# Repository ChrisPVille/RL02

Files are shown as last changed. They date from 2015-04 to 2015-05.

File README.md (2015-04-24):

# RL02-USB Interface Project

## Overview

The aim of this project is to create an open-source interface between the DEC RL02 and a modern computer via USB.  

## Background

The RL02 hard drive was a mainstay of DEC's packaged computer systems in the late 1970s and 1980s.  Storing 10MB of data, these drives featured removable platters, 55ms average seek times, and ~250KBps effective linear throughput.  Combined with the modular design and longevity of the product line, there are still many functioning drives and many disk packs out there.

Of course, to interact with the data on these disk packs, a functioning drive is not enough.  Cables, interface cards, a DEC minicomputer, and software are all required, some of which has become very rare and prohibitively expensive when available.  The most cost-effective (and educational!) solution was to create a new interface connecting the drive directly to a [simulated minicomputer](http://simh.trailing-edge.com/) running on a PC.

In addition to the historical preservation aspects, people still operate vintage computers for fun and profit.  Setting up an operating system or transferring files can be an ordeal when they can only be moved via [Kermit](http://en.wikipedia.org/wiki/Kermit_%28protocol%29) or some other archaic medium.  This interface serves to obviate the need for such things by allowing the direct interface of the RL02 with a modern computer.

## The Interface

This interface uses an FPGA to do all drive-facing tasks such as MFM data decoding, clock recovery, drive state management, data buffering, etc.  The FPGA communicates with a microcontroller, exposing its data and a command interface over SPI.  That microcontroller serves as the USB mass storage/bulk transport device for the attached PC.

### FPGA

TODO: Expand

### Microcontroller

TODO: Expand

### PCB

TODO: Expand

## How to Update

```shell
echo TODO
```

## Building The Sources

TODO: Expand

(C) 2015 Christopher Parish

This program is free software: you can redistribute it and/or modify
it under the terms of the GNU General Public License as published by
the Free Software Foundation, either version 3 of the License, or
(at your option) any later version.  This is subject to the
exceptions listed in the LICENSE_EXCEPTION file.

This program is distributed in the hope that it will be useful,
but WITHOUT ANY WARRANTY; without even the implied warranty of
MERCHANTABILITY or FITNESS FOR A PARTICULAR PURPOSE.  See the
GNU General Public License for more details.

You should have received a copy of the GNU General Public License
along with this program.  If not, see <http://www.gnu.org/licenses/>.

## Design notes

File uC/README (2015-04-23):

Here is the Texas Instruments Code Composer Studio project used on the ARM micro-controller.  This is in prototype condition, suitable for trying different communication approaches and not architected in any particular manner (i.e. a complete mess).

In addition to CCS (http://processors.wiki.ti.com/index.php/Download_CCS), you will require the Tivaware Peripheral Driver Library and USB Library packages from TI (http://www.ti.com/tool/sw-tm4c).  On Linux, these EXEs can be sent to unzip directly.

I would prefer to host the drivers here, but TI has some hideous licensing verbiage on their drivers, preventing redistribution.  I might move away from them in the future because of it.

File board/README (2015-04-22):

This folder contains the KiCad (https://launchpad.net/kicad) project files, schematic symbols, and related footprints as well as generated schematics and gerber files.

I generally run the latest KiCad built from sources, so I may be using features that don't exist in the pre-built versions.

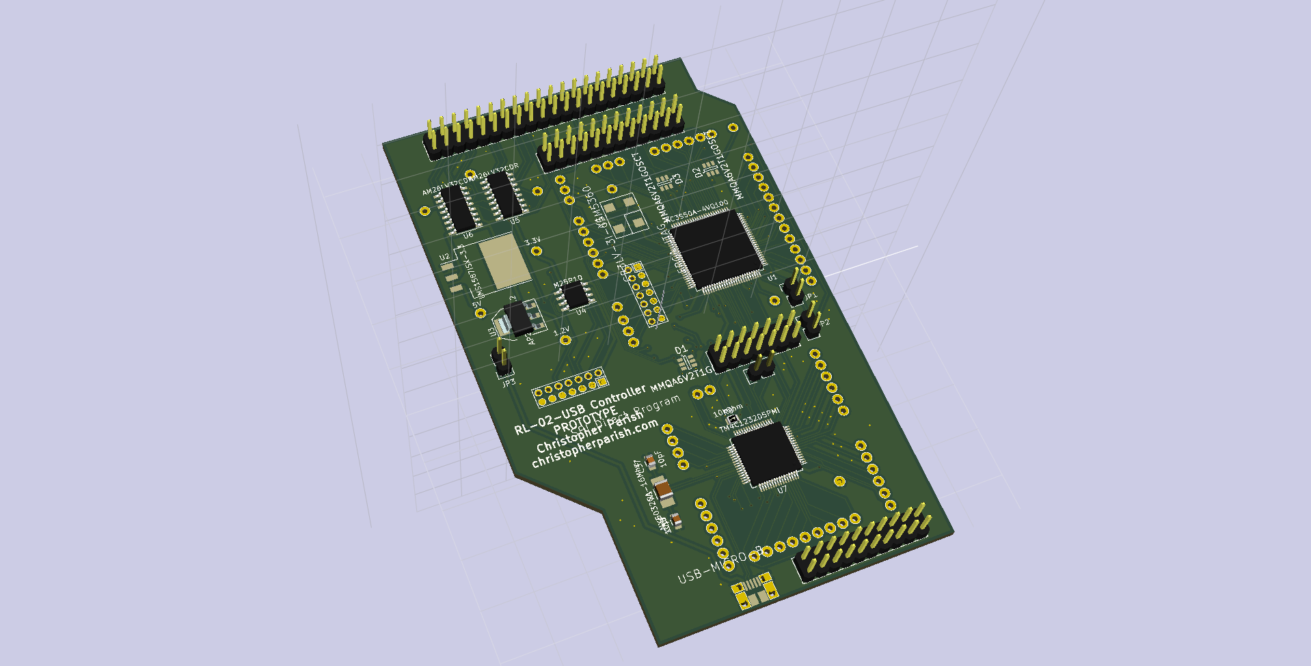
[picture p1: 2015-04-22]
board/Renders/First Prototype F.png

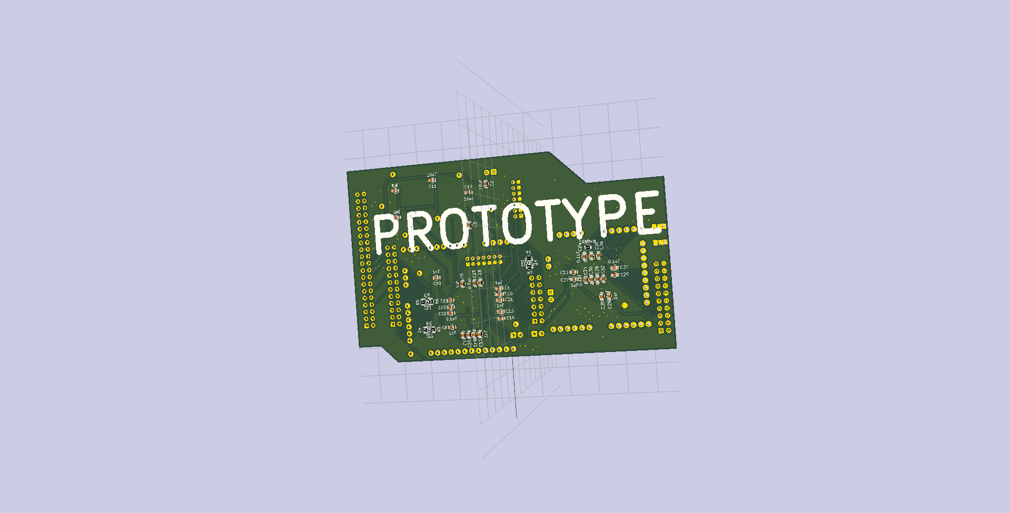
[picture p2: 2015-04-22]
board/Renders/First Prototype B.png

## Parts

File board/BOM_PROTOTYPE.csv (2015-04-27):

Digi-Key Part Number | Manufacturer | Manufacturer Part Number | Customer Reference | Quantity 1 | Quantity 2 | Quantity 3 | Mfg Std Lead Time | Description | Comments | RoHS Status | Lead Free Status | REACH Status
122-1592-ND | XILINX INC | XC3S50A-4VQG100C | MAIN FPGA | 1 | 0 | 0 | 18 Weeks | IC FPGA 68 I/O 100VQFP |  | RoHS Compliant | Lead free | Unaffected Dec-2014
296-35812-ND | TEXAS INSTRUMENTS | TM4C1232D5PMI | MAIN UC | 1 | 0 | 0 | 16 Weeks | IC MCU 32BIT 64KB FLASH 64LQFP | Alternate Packaging Exists | RoHS Compliant | Lead free | Unaffected Dec-2014
296-6794-1-ND | TEXAS INSTRUMENTS (VA) | AM26LV32CDR | DIFF RX | 2 | 0 | 0 | 6 Weeks | IC QUAD DIFF LINE RCVR 16-SOIC | Alternate Packaging Exists | RoHS Compliant | Lead free | Unaffected Dec-2014
CTX713LVCT-ND | CTS-FREQUENCY CONTROLS (VA) | CB3LV-3I-65M5360 | FPGA CLK | 1 | 0 | 0 | 6 Weeks | OSC XO 65.536MHZ HCMOS TTL SMD | Alternate Packaging Exists | RoHS Compliant | Lead free | Unaffected Jul-2011
AP2114HA-1.2TRG1DICT-ND | DIODES INCORPORATED (VA) | AP2114HA-1.2TRG1 | 1.2V LDO | 1 | 0 | 0 | 9 Weeks | IC REG LDO 1.2V 1A SOT223 | Alternate Packaging Exists | RoHS Compliant | Lead free | Unaffected Dec-2014
M25P10-AVMN6TPCT-ND | MICRON TECHNOLOGY INC (VA) | M25P10-AVMN6TP | FPGA FLASH | 1 | 0 | 0 | 12 Weeks | IC FLASH 1MBIT 50MHZ 8SO | Alternate Packaging Exists | RoHS Compliant | Lead free | Unaffected Aug-2011
644-1187-1-ND | NDK (VA) | NX5032GA-16MHZ-STD-CSK-4 | UC CRYSTAL | 1 | 0 | 0 | 8 Weeks | CRYSTAL 16.0000MHZ 8PF SMD | Alternate Packaging Exists | RoHS Compliant | Lead free by exemption | Unaffected Dec-2014
587-3512-1-ND | TAIYO YUDEN (VA) | UMK212BJ104KGHT |  | 12 | 0 | 0 | 5 Weeks | CAP CER 0.1UF 50V 10% X5R 0805 | Alternate Packaging Exists | RoHS Compliant | Lead free | Not Available
587-1300-1-ND | TAIYO YUDEN (VA) | LMK212BJ106KG-T |  | 4 | 0 | 0 | 5 Weeks | CAP CER 10UF 10V 10% X5R 0805 | Alternate Packaging Exists | RoHS Compliant | Lead free | Unaffected Nov-2009
587-1293-1-ND | TAIYO YUDEN (VA) | EMK212BJ225KG-T |  | 2 | 0 | 0 | 5 Weeks | CAP CER 2.2UF 16V 10% X5R 0805 | Alternate Packaging Exists | RoHS Compliant | Lead free | Unaffected Nov-2009
587-1291-1-ND | TAIYO YUDEN (VA) | TMK212BJ105KG-T |  | 25 | 0 | 0 | 5 Weeks | CAP CER 1UF 25V 10% X5R 0805 | Alternate Packaging Exists | RoHS Compliant | Lead free | Unaffected Nov-2009
609-3491-ND | FCI | 67996-114HLF | SPI JUMPERS | 1 | 0 | 0 | 6 Weeks | BERGSTIK II .100" DR STRAIGHT |  | RoHS Compliant | Lead free | Unaffected Dec-2012
609-3395-ND | FCI | 67997-224HLF | DRIVE DISCONNECT HEADER | 1 | 0 | 0 | 6 Weeks | CONN HEADER 24POS .100 STR 15AU |  | RoHS Compliant | Lead free | Unaffected Dec-2012
S9175-ND | SULLINS CONNECTOR SOLUTIONS | SBH11-PBPC-D20-ST-BK | DRIVE CONNECTOR | 1 | 0 | 0 | 4 Weeks | CONN HEADER 2.54MM 40POS GOLD |  | RoHS Compliant | Lead free | Unaffected Dec-2014
609-4050-1-ND | FCI (VA) | 10103594-0001LF |  | 1 | 0 | 0 | 9 Weeks | CONN RCPT STD MICRO USB TYPE B | Alternate Packaging Exists | RoHS Compliant | Lead free | Unaffected Dec-2012
311-1099-1-ND | YAGEO (VA) | CC0805JRNPO9BN100 |  | 3 | 0 | 0 | 20 Weeks | CAP CER 10PF 50V 5% NPO 0805 | Alternate Packaging Exists | RoHS Compliant | Lead free | Unaffected Jun-2014
311-10.0KCRCT-ND | YAGEO (VA) | RC0805FR-0710KL |  | 3 | 0 | 0 | 22 Weeks | RES SMD 10K OHM 1% 1/8W 0805 | Alternate Packaging Exists | RoHS Compliant | Lead free | Unaffected Jun-2014
S9172-ND | SULLINS CONNECTOR SOLUTIONS | SBH11-PBPC-D10-ST-BK | UC JTAG | 1 | 0 | 0 | 4 Weeks | CONN HEADER 2.54MM 20POS GOLD |  | RoHS Compliant | Lead free | Unaffected Dec-2014
MMQA6V2T1GOSCT-ND | ON SEMICONDUCTOR (VA) | MMQA6V2T1G | ESD DIODES | 3 | 0 | 0 | 4 Weeks | TVS DIODE 4VWM 9VC SC74-6 | Alternate Packaging Exists | RoHS Compliant | Lead free | Unaffected Dec-2014
AP2114H-3.3TRG1DICT-ND | DIODES INCORPORATED (VA) | AP2114H-3.3TRG1 | 3.3V REG | 1 | 0 | 0 | 9 Weeks | IC REG LDO 3.3V 1A SOT223 | Alternate Packaging Exists | RoHS Compliant | Lead free | Unaffected Dec-2014
RHM330KCT-ND | ROHM SEMICONDUCTOR (PASSIVE) (VA) | ESR10EZPJ331 | TERMINATION RESISTORS | 26 | 0 | 0 | 6-8 Weeks | RES SMD 330 OHM 5% 0.4W 0805 | Alternate Packaging Exists | RoHS Compliant | Lead free | Unaffected Jun-2012

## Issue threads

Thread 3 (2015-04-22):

Bad sector remapping in USB MSC mode

ChrisPVille, 2015-04-22:
Modern OSes get unhappy when they have to deal with IO errors from disks.  The RL02 disk packs pretty much all had bad sectors somewhere.  These can be identified and stored in a factory provided table on the last track of the disk, but it was up to each OS to decide how to handle them.  Some skip sectors while others remap them.

In USB Mass Storage mode, save a track of the RL02 for sector remapping and use the DEC written bad sector table.  With these, modern filesystems can be written to the disk around the inevitable bad sectors, although this will break SIMH and block level disk backup support for vintage disks.

smaresca, 2017-04-14:
@ChrisPVille I'm curious: have you revisited this item by any chance?

ChrisPVille, 2017-05-14:
Nope. I haven't worked on the hard drive project in a while.  It was becoming a major headache to constantly repair the age-related problems that kept popping up in the drive as I was trying to build this.  I did pick up a few more RL-02s in the interim, and I will get back to working on this... eventually.

As far as the bad sector map, I don't think it needs to be in the DEC format.  I suspect any drive being used in MSC mode is not ever going to be fully compatible with the PDP-11 emulators.  Because the emulated software (RT-11, etc.) handles bad sectors internally, it would be an ugly process of decoding the DEC bad sector format on the disk, managing that from the microcontroller, communicating that through a side-channel to a modified SimH which would feed that through to the guest OS where any failing writes to bad sectors would get communicated back to the uC for inclusion on that table.

It makes more sense to have MSC mode (LBA) available for modern filesystems which can handle their own bad blocks and provide a special SimH driver exposing the underlying Cylinder Head Sector format a virtual RL11 controller would have.  The microcontroller never has to worry about marking or relocating bad blocks as higher level pieces of software will do that.

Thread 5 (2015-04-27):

Incorrect 3.3V Regulator

ChrisPVille, 2015-04-27:
The BOM has the wrong 3.3V regulator specified for the physical footprint.

Either find a pin compatible replacement or pick a new part.

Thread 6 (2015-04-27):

Anomalous drive fault after spindown

ChrisPVille, 2015-04-27:
Every once in a while the drive asserts a non-resettable fault after sitting idle, post-spindown, for a while.  It seems to spontaneously disappear before I go to probe it.  It might be an electrical margin issue.

Write some code and modify the FPGA to interrupt the microcontroller so it can capture the error condition the instant it happens, before it goes away.  This type of error handing will be required for robustness anyway.

ChrisPVille, 2015-05-03:
Quickly poking around, it looks like spin error gets asserted by the drive.  This is probably an issue with the actual drive logic board, as spin error isn't supposed to assert on spin-down (because that would be dumb).

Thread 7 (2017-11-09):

RL02 Terminator - is it necessary?

AaronJackson, 2017-11-09:
Hi Chris,
I saw the video about this project on Hackaday and it didn't look like you had a terminator attached. Is one actually needed? I've been trying to get an RL02 drive to work with my 11/73 but not having much luck. Thanks and great job with this project.

ChrisPVille, 2017-11-10:
The cable run between my controller card and the drive was around 15cm, under any length where I needed to worry about transmission line effects.  Like the DEC RL11, my controller card has termination resistors on it, which should help quell reflections somewhat.

The system clock is a leisurely 4.1Mhz although the write MFM signal should probably be modeled as ~100Mhz because of the tiny phase shifts caused by write pre-compensation.  Still, at 100Mhz the drive will probably work sans terminator read/write with cable lengths in the low 10s of cm and read-only out over a meter.  As with all things RF, YMMV.

If you find you really need a terminator and can't find an official one (it took me two years to find one), you can build a PCB with the appropriate value termination resistors and connect the internal ribbon cable to it as I believe @NF6X did for his RL-02 interface project [here](https://github.com/NF6X/RL02-USB/tree/master/pcbs/RL02-USB-terminator).

AaronJackson, 2017-11-10:
Thanks Chris. That's very useful information. I had tried building a terminator but I am beginning to think I'm either very bad at geometry or there is an issue with the drive.

Closed 2017-11-10.

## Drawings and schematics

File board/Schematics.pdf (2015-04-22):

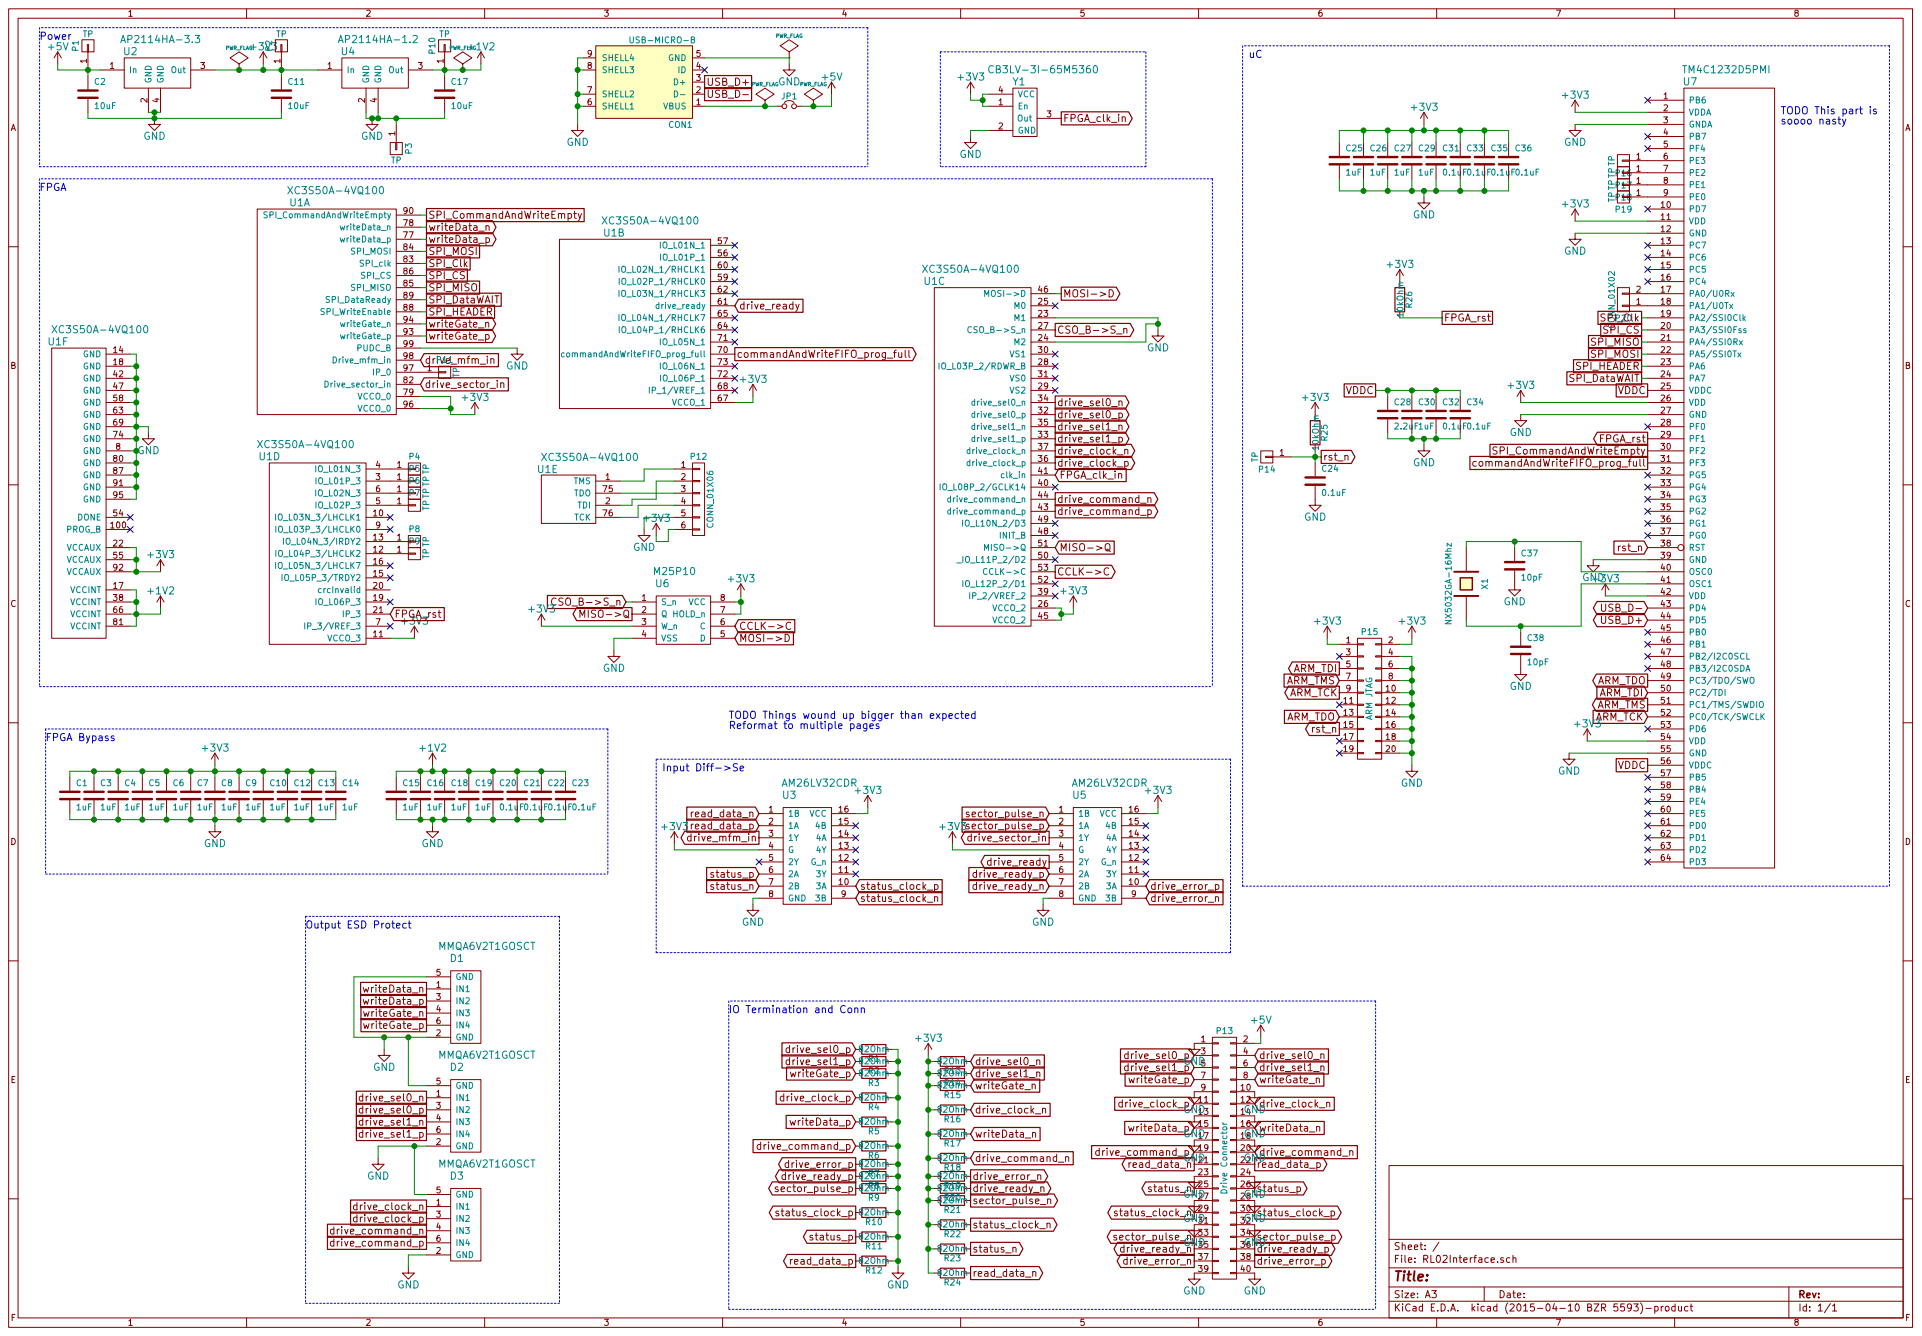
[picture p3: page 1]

4 U2AP2114HA-3.3 TODO This part is

TODO Things wound up bigger than expected
Reformat to multiple pages

Id: 1/1 Title: File: RL02Interface.sch Sheet: /

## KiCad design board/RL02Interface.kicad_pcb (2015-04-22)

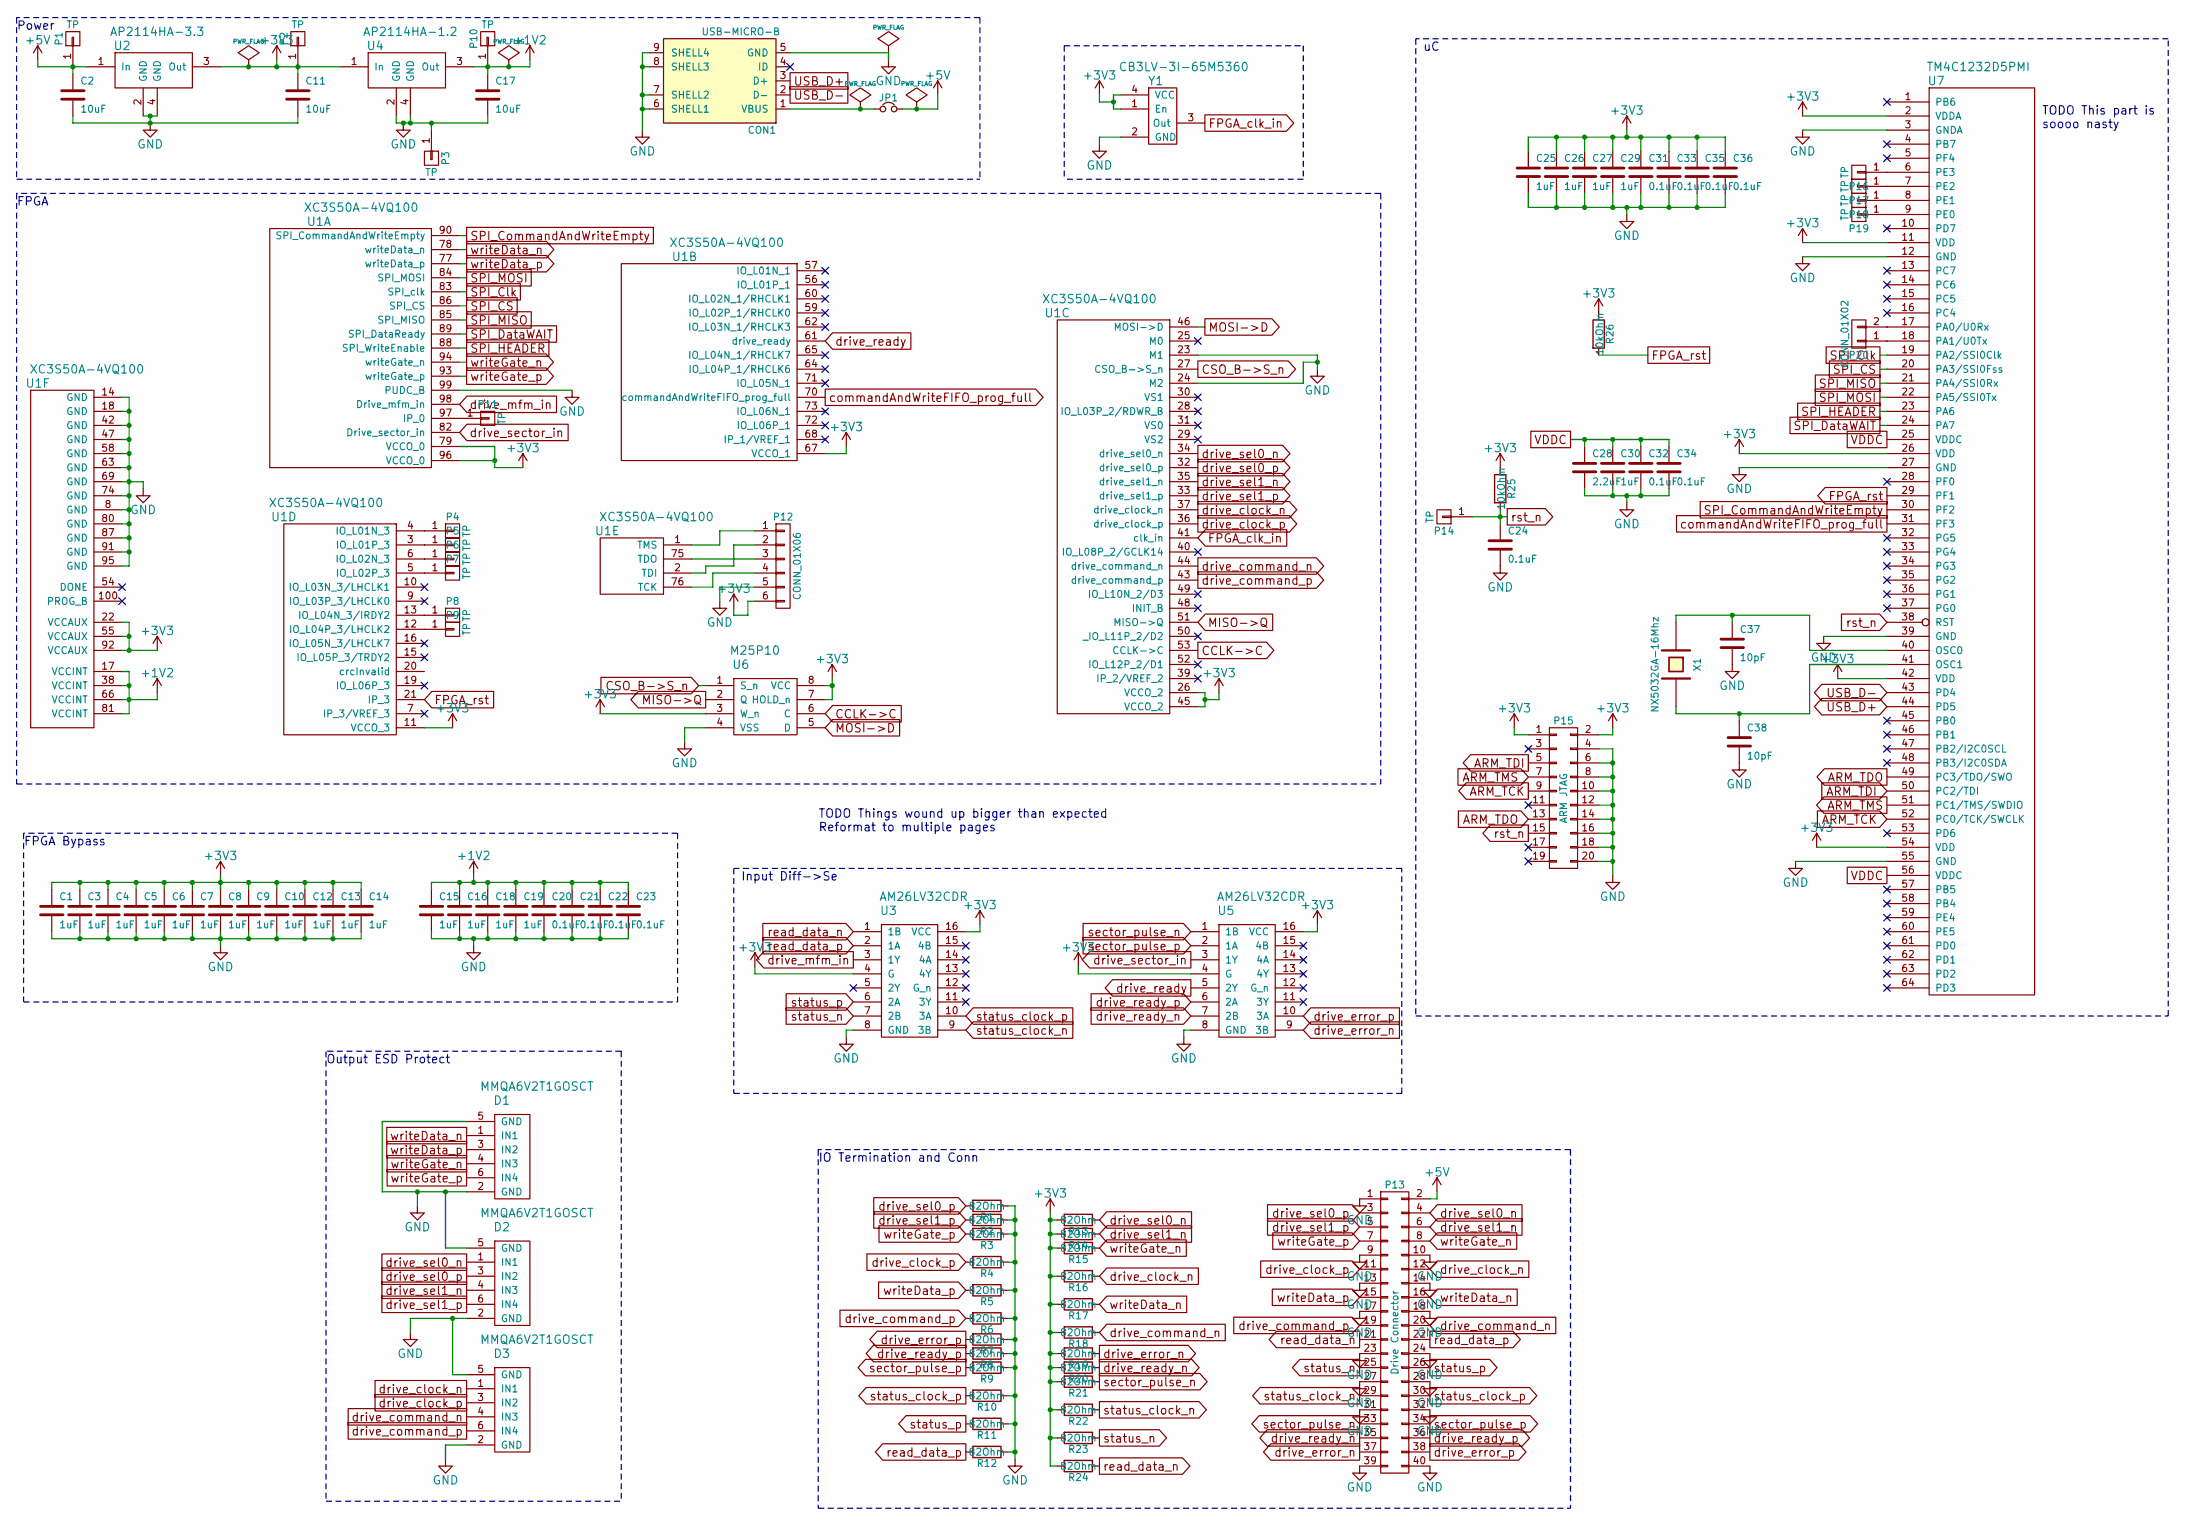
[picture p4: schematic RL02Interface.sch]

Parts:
C1, C3, C4, C5, C6, C7, C8, C9, C10, C12, C13, C14, C15, C16, C18, C19, C25, C26, C27, C29, C30: 1uF; C_0805
C2, C11, C17: 10uF; C_0805
C20, C21, C22, C23, C24, C31, C32, C33, C34, C35, C36: 0.1uF; C_0805
C28: 2.2uF; C_0805
C37, C38: 10pF; C_0805
CON1: USB-MICRO-B; MicroUSB-B
D1, D2, D3: MMQA6V2T1GOSCT; SOT-23-6
JP1: Jumper_NC_Small; Pin_Header_Straight_1x02
P1, P2, P3, P4, P5, P6, P7, P8, P9, P10, P11, P14, P16, P17, P18, P19: TP
P12: CONN_01X06; Pin_Header_Straight_1x06
P13: Drive Connector; Pin_Header_Straight_2x20
P15: ARM JTAG; Pin_Header_Straight_2x10
P20: CONN_01X02; Pin_Header_Straight_1x02
R1, R2, R3, R4, R5, R6, R7, R8, R9, R10, R11, R12, R13, R14, R15, R16, R17, R18, R19, R20, R21, R22, R23, R24: 82Ohm; R_0805
R25, R26: 10kOhm; R_0805
U1: XC3S50A-4VQ100; TQFP-100_14x14mm_Pitch0.5mm
U2: AP2114HA-3.3; SOT-223
U3, U5: AM26LV32CDR; SOIC-16_3.9x9.9mm_Pitch1.27mm
U4: AP2114HA-1.2; SOT-223
U6: M25P10; SOIC-8_3.9x4.9mm_Pitch1.27mm
U7: TM4C1232D5PMI; TQFP-64_10x10mm_Pitch0.5mm
X1: NX5032GA-16Mhz; C_1210_HandSoldering
Y1: CB3LV-3I-65M5360; CTSCrystal

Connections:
+1V2: C15.1, C16.1, C17.1, C18.1, C19.1, C20.1, C21.1, C22.1, C23.1, P10.1, U1.17 (VCCINT), U1.38 (VCCINT), U1.66 (VCCINT), U1.81 (VCCINT), U4.3 (Out); also elsewhere on the board
+3V3: C1.1, C3.1, C4.1, C5.1, C6.1, C7.1, C8.1, C9.1, C10.1, C11.1, C12.1, C13.1, C14.1, C25.1, C26.1, C27.1, C29.1, C31.1, C33.1, C35.1, C36.1, P2.1, P12.6, P15.1, P15.2, R13.2, R14.2, R15.2, R16.2, R17.2, R18.2, R19.2, R20.2, R21.2, R22.2, R23.2, R24.2, R25.1, R26.1, U1.11 (VCCO_3), U1.22 (VCCAUX), U1.26 (VCCO_2), U1.45 (VCCO_2), U1.55 (VCCAUX), U1.67 (VCCO_1), U1.79 (VCCO_0), U1.92 (VCCAUX), U1.96 (VCCO_0), U2.3 (Out), U3.4 (G), U3.16 (VCC), U4.1 (In), U5.4 (G), U5.16 (VCC), U6.3 (W_n), U6.7 (HOLD_n), U6.8 (VCC), U7.2 (VDDA), U7.11 (VDD), U7.26 (VDD), U7.42 (VDD), U7.54 (VDD), Y1.1 (En), Y1.4 (VCC); also elsewhere on the board
+5V: C2.1, JP1.2, P1.1, P13.2, U2.1 (In); also elsewhere on the board
ARM_TCK: P15.9, U7.52 (PC0/TCK/SWCLK)
ARM_TDI: P15.5, U7.50 (PC2/TDI)
ARM_TDO: P15.13, U7.49 (PC3/TDO/SWO)
ARM_TMS: P15.7, U7.51 (PC1/TMS/SWDIO)
CCLK->C: U1.53 (CCLK->C), U6.6 (C)
CSO_B->S_n: U1.27 (CSO_B->S_n), U6.1 (S_n)
FPGA_clk_in: U1.41 (clk_in), Y1.3 (Out)
FPGA_rst: R26.2, U1.21 (IP_3), U7.29 (PF1)
GND: C1.2, C2.2, C3.2, C4.2, C5.2, C6.2, C7.2, C8.2, C9.2, C10.2, C11.2, C12.2, C13.2, C14.2, C15.2, C16.2, C17.2, C18.2, C19.2, C20.2, C21.2, C22.2, C23.2, C24.2, C25.2, C26.2, C27.2, C28.2, C29.2, C30.2, C31.2, C32.2, C33.2, C34.2, C35.2, C36.2, C37.2, C38.2, CON1.5 (GND), CON1.6 (SHELL1), CON1.7 (SHELL2), CON1.8 (SHELL3), CON1.9 (SHELL4), CON1.PAD, D1.2 (GND), D1.5 (GND), D2.2 (GND), D2.5 (GND), D3.2 (GND), D3.5 (GND), P3.1, P12.5, P13.1, P13.9, P13.10, P13.13, P13.14, P13.17, P13.18, P13.23, P13.24, P13.27, P13.28, P13.31, P13.32, P13.39, P13.40, P15.4, P15.6, P15.8, P15.10, P15.12, P15.14, P15.16, P15.18, P15.20, R1.1, R2.1, R3.1, R4.1, R5.1, R6.1, R7.1, R8.1, R9.1, R10.1, R11.1, R12.1, U1.8 (GND), U1.14 (GND), U1.18 (GND), U1.23 (M1), U1.24 (M2), U1.42 (GND), U1.47 (GND), U1.58 (GND), U1.63 (GND), U1.69 (GND), U1.74 (GND), U1.80 (GND), U1.87 (GND), U1.91 (GND), U1.95 (GND), U1.99 (PUDC_B), U2.2 (GND), U2.4 (GND), U3.8 (GND), U4.2 (GND), U4.4 (GND), U5.8 (GND), U6.4 (VSS), U7.3 (GNDA), U7.12 (GND), U7.27 (GND), U7.39 (GND), U7.55 (GND), Y1.2 (GND); also elsewhere on the board
MISO->Q: U1.51 (MISO->Q), U6.2 (Q)
MOSI->D: U1.46 (MOSI->D), U6.5 (D)
unnamed: C37.1, U7.40 (OSC0), X1.1
unnamed: C38.1, U7.41 (OSC1), X1.2
unnamed: CON1.1 (VBUS), JP1.1
unnamed: P4.1, U1.4 (IO_L01N_3)
unnamed: P5.1, U1.3 (IO_L01P_3)
unnamed: P6.1, U1.6 (IO_L02N_3)
unnamed: P7.1, U1.5 (IO_L02P_3)
unnamed: P8.1, U1.13 (IO_L04N_3/IRDY2)
unnamed: P9.1, U1.12 (IO_L04P_3/LHCLK2)
unnamed: P11.1, U1.97 (IP_0)
unnamed: P12.1, U1.1 (TMS)
unnamed: P12.2, U1.2 (TDI)
unnamed: P12.3, U1.75 (TDO)
unnamed: P12.4, U1.76 (TCK)
unnamed: P16.1, U7.6 (PE3)
unnamed: P17.1, U7.7 (PE2)
unnamed: P18.1, U7.8 (PE1)
unnamed: P19.1, U7.9 (PE0)
unnamed: P20.1, U7.18 (PA1/U0Tx)
unnamed: P20.2, U7.17 (PA0/U0Rx)
SPI_CS: U1.86 (SPI_CS), U7.20 (PA3/SSI0Fss)
SPI_Clk: U1.83 (SPI_clk), U7.19 (PA2/SSI0Clk)
SPI_CommandAndWriteEmpty: U1.90 (SPI_CommandAndWriteEmpty), U7.30 (PF2)
SPI_DataWAIT: U1.89 (SPI_DataReady), U7.24 (PA7)
SPI_HEADER: U1.88 (SPI_WriteEnable), U7.23 (PA6)
SPI_MISO: U1.85 (SPI_MISO), U7.21 (PA4/SSI0Rx)
SPI_MOSI: U1.84 (SPI_MOSI), U7.22 (PA5/SSI0Tx)
USB_D+: CON1.3 (D+), U7.44 (PD5)
USB_D-: CON1.2 (D-), U7.43 (PD4)
VDDC: C28.1, C30.1, C32.1, C34.1, U7.25 (VDDC), U7.56 (VDDC)
commandAndWriteFIFO_prog_full: U1.70 (commandAndWriteFIFO_prog_full), U7.31 (PF3)
drive_clock_n: D3.1 (IN1), P13.12, R16.1, U1.37 (drive_clock_n)
drive_clock_p: D3.3 (IN2), P13.11, R4.2, U1.36 (drive_clock_p)
drive_command_n: D3.4 (IN3), P13.20, R18.1, U1.44 (drive_command_n)
drive_command_p: D3.6 (IN4), P13.19, R6.2, U1.43 (drive_command_p)
drive_error_n: P13.37, R19.1, U5.9 (3B)
drive_error_p: P13.38, R7.2, U5.10 (3A)
drive_mfm_in: U1.98 (Drive_mfm_in), U3.3 (1Y)
drive_ready: U1.61 (drive_ready), U5.5 (2Y)
drive_ready_n: P13.35, R20.1, U5.7 (2B)
drive_ready_p: P13.36, R8.2, U5.6 (2A)
drive_sector_in: U1.82 (Drive_sector_in), U5.3 (1Y)
drive_sel0_n: D2.1 (IN1), P13.4, R13.1, U1.34 (drive_sel0_n)
drive_sel0_p: D2.3 (IN2), P13.3, R1.2, U1.32 (drive_sel0_p)
drive_sel1_n: D2.4 (IN3), P13.6, R14.1, U1.35 (drive_sel1_n)
drive_sel1_p: D2.6 (IN4), P13.5, R2.2, U1.33 (drive_sel1_p)
read_data_n: P13.21, R24.1, U3.1 (1B)
read_data_p: P13.22, R12.2, U3.2 (1A)
rst_n: C24.1, P14.1, P15.15, R25.2, U7.38 (RST); also elsewhere on the board
sector_pulse_n: P13.33, R21.1, U5.1 (1B)
sector_pulse_p: P13.34, R9.2, U5.2 (1A)
status_clock_n: P13.29, R22.1, U3.9 (3B)
status_clock_p: P13.30, R10.2, U3.10 (3A)
status_n: P13.25, R23.1, U3.7 (2B)
status_p: P13.26, R11.2, U3.6 (2A)
writeData_n: D1.1 (IN1), P13.16, R17.1, U1.78 (writeData_n)
writeData_p: D1.3 (IN2), P13.15, R5.2, U1.77 (writeData_p)
writeGate_n: D1.4 (IN3), P13.8, R15.1, U1.94 (writeGate_n)
writeGate_p: D1.6 (IN4), P13.7, R3.2, U1.93 (writeGate_p)

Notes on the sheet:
TODO This part is soooo nasty
TODO Things wound up bigger than expected Reformat to multiple pages
FPGA
Power
FPGA Bypass
Output ESD Protect
IO Termination and Conn
Input Diff->Se

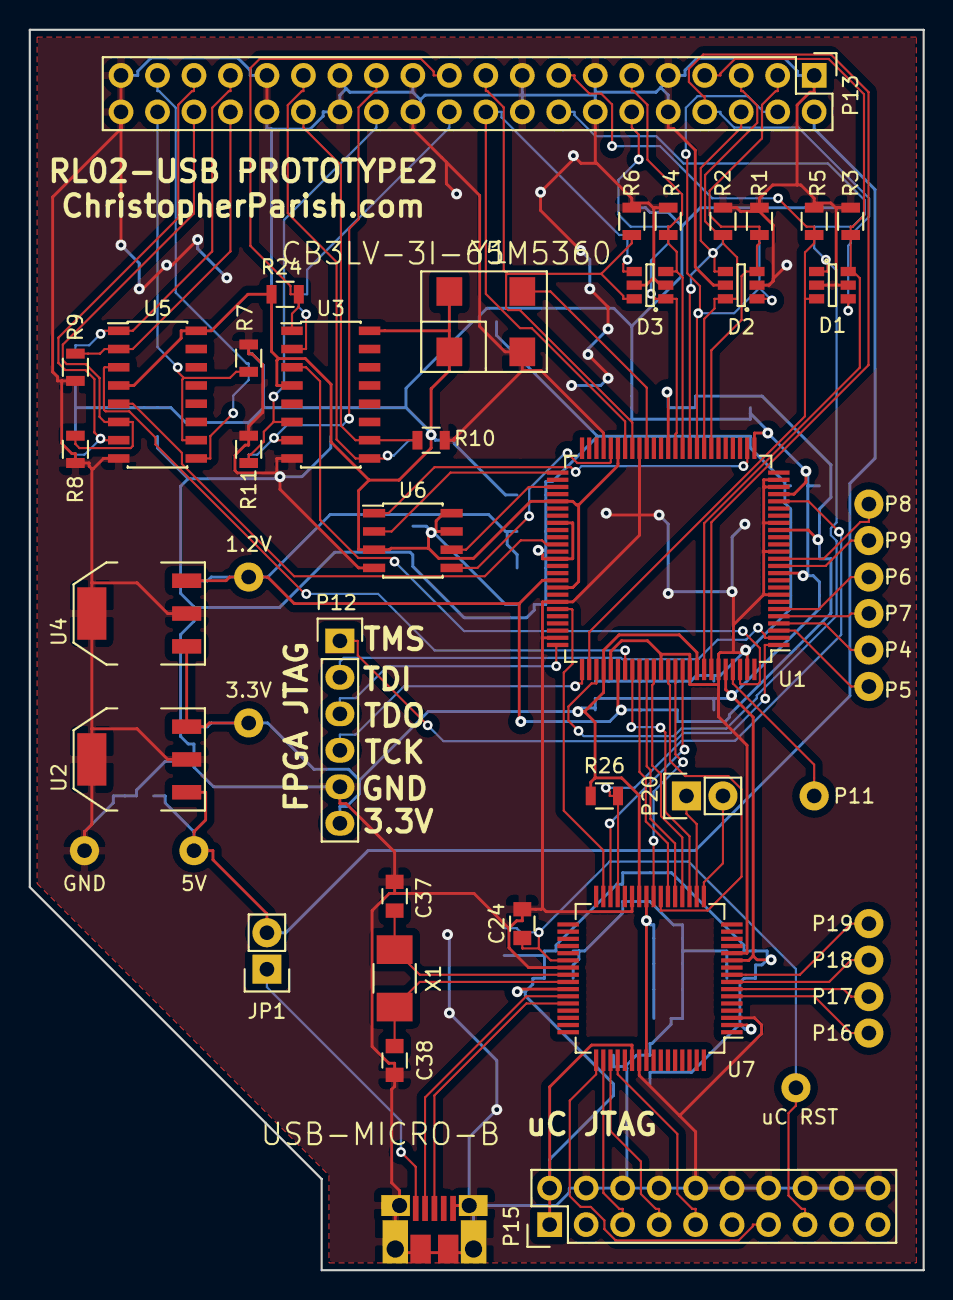
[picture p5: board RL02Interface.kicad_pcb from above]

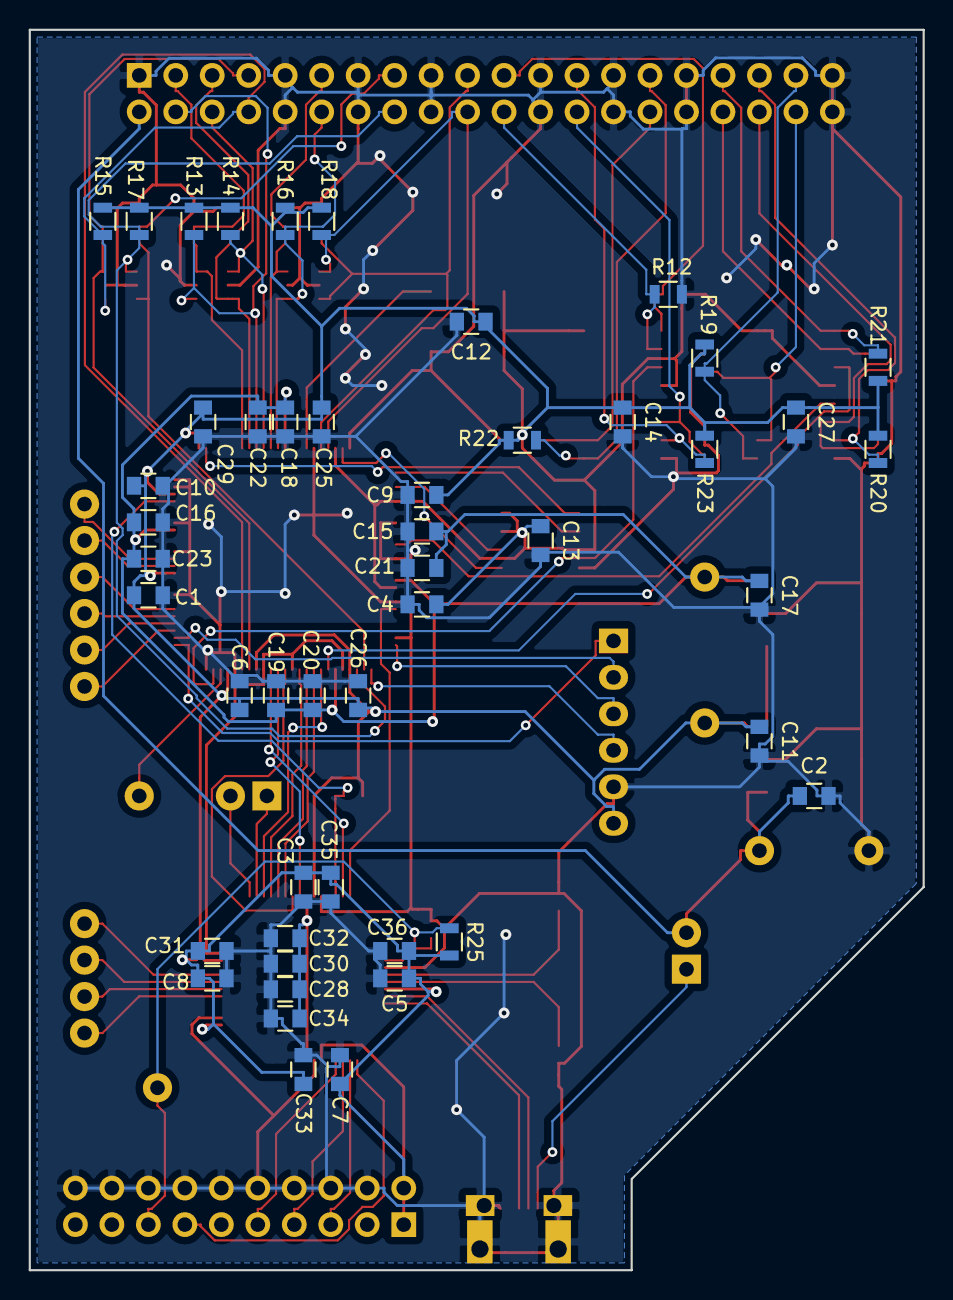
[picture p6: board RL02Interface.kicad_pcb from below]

Board: 2 copper layers, 62.2 x 86.4 mm, 98 parts (48 on the bottom side), 73 nets.

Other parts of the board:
1.2V, 3.3V, 5V: TP
GND: TP
uC RST: TP

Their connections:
+1V2: 1.2V.1; also elsewhere on the board
+3V3: 3.3V.1; also elsewhere on the board
+5V: 5V.1; also elsewhere on the board
GND: GND.1; also elsewhere on the board
rst_n: uC RST.1; also elsewhere on the board

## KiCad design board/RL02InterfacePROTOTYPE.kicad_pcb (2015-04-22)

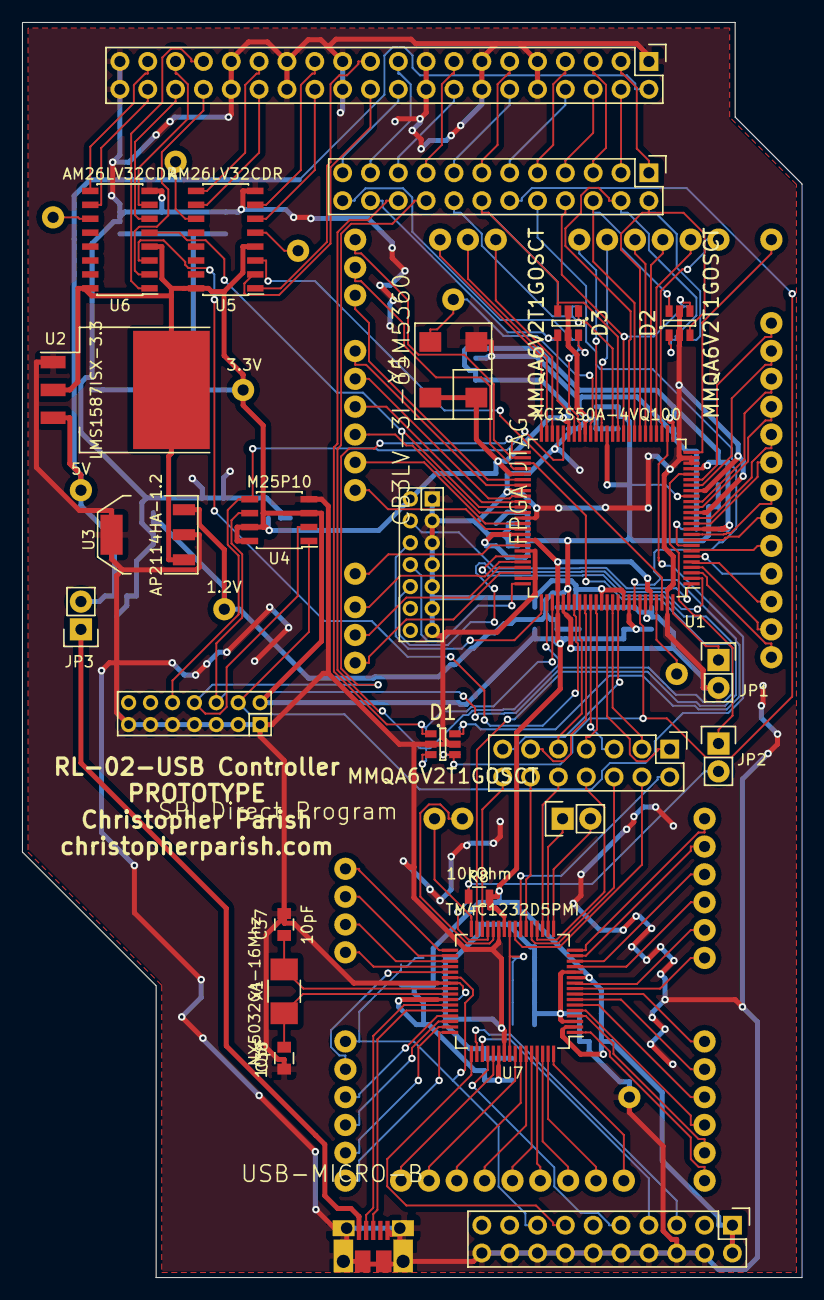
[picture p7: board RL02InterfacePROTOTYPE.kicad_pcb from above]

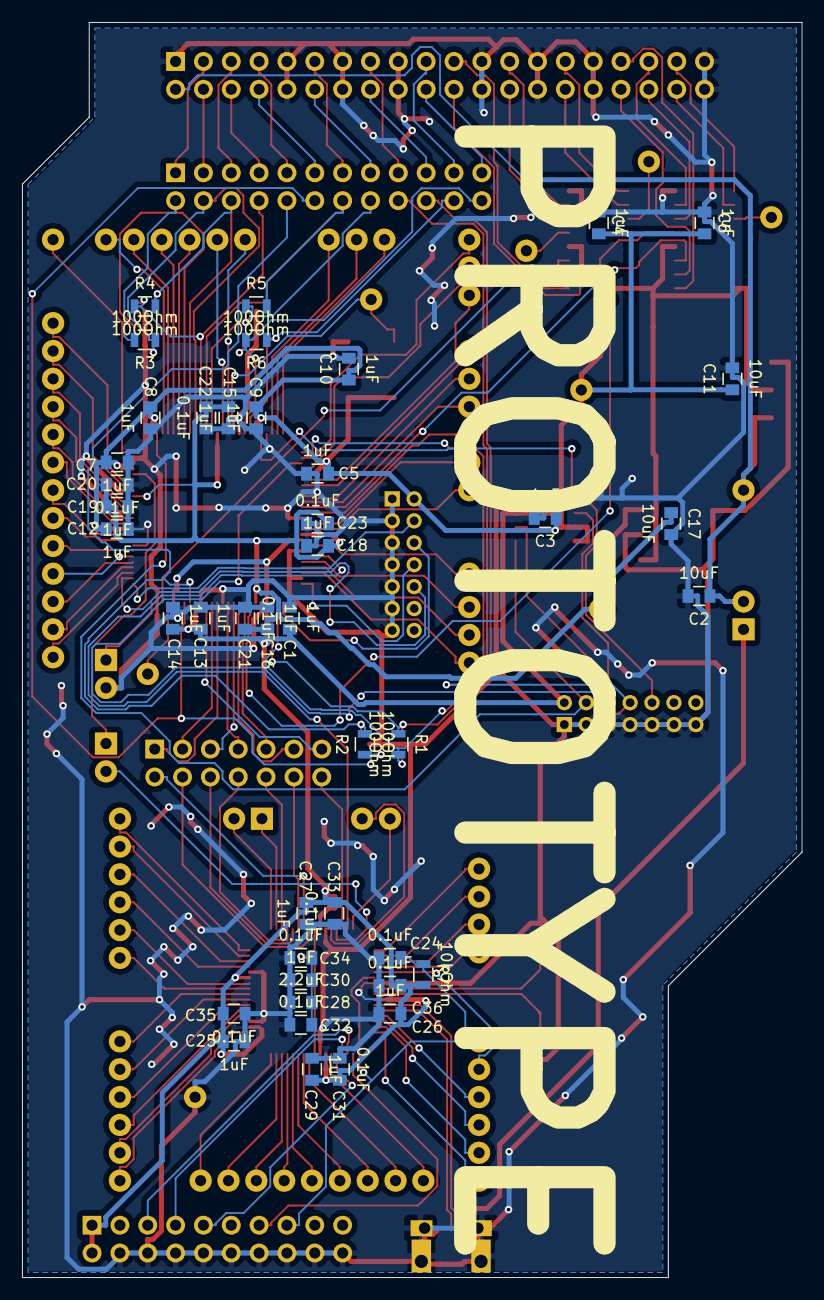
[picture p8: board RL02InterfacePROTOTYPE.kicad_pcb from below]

Board: 2 copper layers, 71.1 x 114.5 mm, 147 parts (43 on the bottom side), 155 nets.

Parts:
1.2V, 3.3V, 5V: TP
C1, C3, C4, C5, C6, C7, C8, C9, C10, C12, C13, C14, C15, C16, C18, C19, C25, C26, C27, C29, C30: 1uF; C_0805
C2, C11, C17: 10uF; C_0805
C20, C21, C22, C23, C24, C31, C32, C33, C34, C35, C36: 0.1uF; C_0805
C28: 2.2uF; C_0805
C37, C38: 10pF; C_0805
CON1: USB-MICRO-B; MicroUSB-B
D1, D2, D3: MMQA6V2T1GOSCT; SOT-23-6
JP1: SPI_PROGRAM; Pin_Header_Straight_1x02
JP2, JP3: JUMPER; Pin_Header_Straight_1x02
P2, P4, P5, P6, P7, P8, P9, P10, P11, P12, P13, P14, P15, P16, P17, P19, P23, P24, P25, P26, P27, P28, P29, P30, P31, P32, P33, P34, P35, P36, P37, P38, P39, P40, P41, P42, P43, P44, P45, P46, P47, P50, P52, P53, P54, P55, P56, P57, P58, P59, P60, P61, P62, P63, P65, P66, P67, P68, P69, P70, P71, P72, P73, P74, P75, P76, P77, P78, P79, P80, P81, P82, P83, P84, P85: TP
P20: SPI Debug; Pin_Header_Straight_2x07
P21: FPGA JTAG; 2x7_2.00mm_header
P22: SPI Direct Program; 2x7_2.00mm_header
P48: Data To Drive Disconnect; Pin_Header_Straight_2x12
P49: Drive Connector; Pin_Header_Straight_2x20
P51: ARM JTAG; Pin_Header_Straight_2x10
P64: CONN_01X02; Pin_Header_Straight_1x02
R1, R2, R3, R4, R5, R6: 100Ohm; R_0805
R7, R8: 10kOhm; R_0805
U1: XC3S50A-4VQ100; TQFP-100_14x14mm_Pitch0.5mm
U2: LMS1587ISX-3.3; TO-263
U3: AP2114HA-1.2; SOT-223
U4: M25P10; SOIC-8_3.9x4.9mm_Pitch1.27mm
U5, U6: AM26LV32CDR; SOIC-16_3.9x9.9mm_Pitch1.27mm
U7: TM4C1232D5PMI; TQFP-64_10x10mm_Pitch0.5mm
X1: NX5032GA-16Mhz; C_1210_HandSoldering
Y1: CB3LV-3I-65M5360; CTSCrystal

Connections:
+1V2: 1.2V.1, C15.1, C16.1, C17.1, C18.1, C19.1, C20.1, C21.1, C22.1, C23.1, U1.17, U1.38, U1.66, U1.81, U3.3
+3V3: 3.3V.1, C1.1, C3.1, C4.1, C5.1, C6.1, C7.1, C8.1, C9.1, C10.1, C11.1, C12.1, C13.1, C14.1, C25.1, C26.1, C27.1, C29.1, C31.1, C33.1, C35.1, C36.1, P21.2, P22.2, P51.1, P51.2, R7.1, R8.1, U1.11, U1.22, U1.26, U1.45, U1.55, U1.67, U1.79, U1.92, U1.96, U2.2, U2.PAD, U3.1, U4.3, U4.7, U4.8, U5.4, U5.16, U6.4, U6.16, U7.2, U7.11, U7.26, U7.42, U7.54, Y1.1, Y1.4
+5V: 5V.1, C2.1, JP3.2, P49.2, U2.3
ARM_TCK: P51.9, U7.52
ARM_TDI: P51.5, U7.50
ARM_TDO: P51.13, U7.49
ARM_TMS: P51.7, U7.51
CCLK->C: P22.6, U1.53, U4.6
CSO_B->S_n: P22.4, U1.27, U4.1
FPGA_clk_in: P66.1, U1.41, Y1.3
FPGA_rst: JP2.2, R8.2, U7.29
GND: C1.2, C2.2, C3.2, C4.2, C5.2, C6.2, C7.2, C8.2, C9.2, C10.2, C11.2, C12.2, C13.2, C14.2, C15.2, C16.2, C17.2, C18.2, C19.2, C20.2, C21.2, C22.2, C23.2, C24.2, C25.2, C26.2, C27.2, C28.2, C29.2, C30.2, C31.2, C32.2, C33.2, C34.2, C35.2, C36.2, C37.2, C38.2, CON1.5, CON1.PAD, D1.2, D1.5, D2.2, D2.5, D3.2, D3.5, JP1.2, P4.1, P21.1, P21.3, P21.5, P21.7, P21.9, P21.11, P21.13, P22.1, P22.3, P22.5, P22.7, P22.9, P22.11, P22.13, P49.1, P49.9, P49.10, P49.13, P49.14, P49.17, P49.18, P49.23, P49.24, P49.27, P49.28, P49.31, P49.32, P49.39, P49.40, P51.4, P51.6, P51.8, P51.10, P51.12, P51.14, P51.16, P51.18, P51.20, U1.8, U1.14, U1.18, U1.23, U1.24, U1.42, U1.47, U1.58, U1.63, U1.69, U1.74, U1.80, U1.87, U1.91, U1.95, U1.99, U2.1, U3.2, U3.4, U4.4, U5.8, U6.8, U7.3, U7.12, U7.27, U7.39, U7.55, Y1.2
MISO->Q: P22.8, U1.51, U4.2
MOSI->D: P22.10, U1.46, U4.5
unnamed: C37.1, U7.40, X1.1
unnamed: C38.1, U7.41, X1.2
unnamed: CON1.1, JP3.1
unnamed: JP1.1, U1.100
unnamed: JP2.1, U1.21
unnamed: P2.1, U1.54
unnamed: P5.1, U1.4
unnamed: P6.1, U1.3
unnamed: P7.1, U1.6
unnamed: P8.1, U1.5
unnamed: P9.1, U1.10
unnamed: P10.1, U1.9
unnamed: P11.1, U1.13
unnamed: P12.1, U1.12
unnamed: P13.1, U1.16
unnamed: P14.1, U1.15
unnamed: P15.1, U1.20
unnamed: P16.1, U1.19
unnamed: P17.1, U1.7
unnamed: P19.1, U1.97
unnamed: P20.1, U1.88
unnamed: P20.3, U1.89
unnamed: P20.5, U1.85
unnamed: P20.7, U1.86
unnamed: P20.9, U1.83
unnamed: P20.11, U1.84
unnamed: P20.13, U1.90
unnamed: P21.4, U1.1
unnamed: P21.6, U1.76
unnamed: P21.8, U1.75
unnamed: P21.10, U1.2
unnamed: P23.1, U1.57
unnamed: P24.1, U1.56
unnamed: P25.1, U1.60
unnamed: P26.1, U1.59
unnamed: P27.1, U1.62
unnamed: P28.1, U1.65
unnamed: P29.1, U1.64
unnamed: P30.1, U1.71
unnamed: P31.1, U1.73
unnamed: P32.1, U1.72
unnamed: P33.1, U1.68
unnamed: P34.1, U1.25
unnamed: P35.1, U1.30
unnamed: P36.1, U1.28
unnamed: P37.1, U1.31
unnamed: P38.1, U1.29
unnamed: P39.1, U1.40
unnamed: P40.1, U1.49
unnamed: P41.1, U1.48
unnamed: P42.1, U1.50
unnamed: P43.1, U1.52
unnamed: P44.1, U1.39
unnamed: P45.1, U5.5
unnamed: P46.1, U5.11
unnamed: P47.1, U6.11
unnamed: P48.1, P49.3
unnamed: P48.3, P49.4
unnamed: P48.5, P49.5
unnamed: P48.7, P49.6
unnamed: P48.9, P49.7
unnamed: P48.11, P49.8
unnamed: P48.13, P49.11
unnamed: P48.15, P49.12
unnamed: P48.17, P49.15
unnamed: P48.19, P49.16
unnamed: P48.21, P49.19
unnamed: P48.23, P49.20
unnamed: P52.1, U7.1
unnamed: P53.1, U7.4
unnamed: P54.1, U7.5
unnamed: P55.1, U7.6
unnamed: P56.1, U7.7
unnamed: P57.1, U7.8
unnamed: P58.1, U7.9
unnamed: P59.1, U7.10
unnamed: P60.1, U7.13
unnamed: P61.1, U7.14
unnamed: P62.1, U7.15
unnamed: P63.1, U7.16
unnamed: P64.1, U7.18
unnamed: P64.2, U7.17
unnamed: P65.1, U7.28
unnamed: P67.1, U7.32
unnamed: P68.1, U7.33
unnamed: P69.1, U7.34
unnamed: P70.1, U7.35
unnamed: P71.1, U7.36
unnamed: P72.1, U7.37
unnamed: P73.1, U7.45
unnamed: P74.1, U7.46
unnamed: P75.1, U7.47
unnamed: P76.1, U7.48
unnamed: P77.1, U7.53
unnamed: P78.1, U7.57
unnamed: P79.1, U7.58
unnamed: P80.1, U7.59
unnamed: P81.1, U7.60
unnamed: P82.1, U7.61
unnamed: P83.1, U7.62
unnamed: P84.1, U7.63
unnamed: P85.1, U7.64
SPI_CS: P20.8, U7.20
SPI_Clk: P20.10, U7.19
SPI_CommandAndWriteEmpty: P20.14, U7.30
SPI_DataReady: P20.4, U7.24
SPI_MISO: P20.6, U7.21
SPI_MOSI: P20.12, U7.22
SPI_WriteEnable: P20.2, U7.23
USB_D+: CON1.3, U7.44
USB_D-: CON1.2, U7.43
VDDC: C28.1, C30.1, C32.1, C34.1, U7.25, U7.56
commandAndWriteFIFO_prog_full: U1.70, U7.31
drive_clock_n: D3.1, P48.16, R5.1, U1.37
drive_clock_p: D3.3, P48.14, R5.2, U1.36
drive_command_n: D3.4, P48.22, R6.1, U1.44
drive_command_p: D3.6, P48.24, R6.2, U1.43
drive_error_n: P49.37, U6.9
drive_error_p: P49.38, U6.10
drive_mfm_in: U1.98, U5.3
drive_ready: U1.61, U6.5
drive_ready_n: P49.35, U6.7
drive_ready_p: P49.36, U6.6
drive_sector_in: U1.82, U6.3
drive_sel0_n: D2.1, P48.4, R3.1, U1.34
drive_sel0_p: D2.3, P48.2, R3.2, U1.32
drive_sel1_n: D2.4, P48.8, R4.1, U1.35
drive_sel1_p: D2.6, P48.6, R4.2, U1.33
read_data_n: P49.21, U5.1
read_data_p: P49.22, U5.2
rst_n: C24.1, P50.1, P51.15, R7.2, U7.38
sector_pulse_n: P49.33, U6.1
sector_pulse_p: P49.34, U6.2
status_clock_n: P49.29, U5.9
status_clock_p: P49.30, U5.10
status_n: P49.25, U5.7
status_p: P49.26, U5.6
writeData_n: D1.1, P48.20, R1.1, U1.78
writeData_p: D1.3, P48.18, R1.2, U1.77
writeGate_n: D1.4, P48.12, R2.1, U1.94
writeGate_p: D1.6, P48.10, R2.2, U1.93

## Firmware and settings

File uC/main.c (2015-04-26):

#include <stdlib.h>
#include <stdbool.h>
#include <stdint.h>

#include "inc/hw_ints.h"
#include "inc/hw_types.h"
#include "inc/hw_memmap.h"

#include "driverlib/gpio.h"
#include "driverlib/pin_map.h"
#include "driverlib/rom.h"
#include "driverlib/ssi.h"
#include "driverlib/sysctl.h"
#include "driverlib/udma.h"
#include "driverlib/usb.h"

#include "usblib/usblib.h"
#include "usblib/usb-ids.h"
#include "usblib/device/usbdevice.h"
#include "usblib/device/usbdmsc.h"

#include "ucpins.h"
#include "USB_MSC_Structures.h"

//DMA control data structure
#if defined(ccs)
#pragma DATA_ALIGN(DMA_Ctl, 1024)
tDMAControlTable DMA_Ctl[64];
#else //GCC et al
tDMAControlTable DMA_Ctl[64] __attribute__ ((aligned(1024)));
#endif

//Any bulk transport events related to PC->uC communication trigger this function
//Again, I don't exactly understand why this is needed architectually, other than
//it being a callback target in the usb library, beyond our control.
uint32_t RxHandler(void *callback, uint32_t event, uint32_t eventMsg, void *eventPtr)
{
    return (0);
}

//Any bulk transport events related to uC->PC communication trigger this function
uint32_t TxHandler(void *callback, uint32_t event, uint32_t eventMsg, void *eventPtr)
{
    return (0);
}

//This function gets called on the completion of USB related service events.
//We can use this callback to light up LEDs or notify the user in other ways.
uint32_t USB_MSC_CallbackEventHandler(void *callback, uint32_t event, uint32_t eventMsg, void *eventPtr)
{
    return (0);
}


int main(void)
{
    //
    // 50Mhz from the 200Mhz PLL with a 16Mhz crystal input.
    //
    SysCtlClockSet(SYSCTL_SYSDIV_4 | SYSCTL_USE_PLL | SYSCTL_OSC_MAIN | SYSCTL_XTAL_16MHZ);

    //Turn on the uDMA engine
    SysCtlPeripheralEnable(SYSCTL_PERIPH_UDMA);
    SysCtlDelay(10);
    uDMAControlBaseSet(&DMA_Ctl[0]);
    uDMAEnable();

    PortFunctionInit();

    GPIOPinWrite(GPIO_PORTF_BASE, GPIO_PIN_1, GPIO_PIN_1); //Put FPGA core into reset (this is the case when not driving the pin).
    GPIOPinWrite(GPIO_PORTA_BASE, GPIO_INT_PIN_6, 0); //De-Assert Write Enable
    SysCtlDelay(SysCtlClockGet() / 30); //Wait ~100ms

    GPIOPinWrite(GPIO_PORTF_BASE, GPIO_PIN_1, 0); //Bring the FPGA out of reset once we start up
    SysCtlDelay(SysCtlClockGet() / 30); //Wait ~100ms

    //Force the uC into USB device mode (the sense pin may not work due to a silicon bug)
    USBStackModeSet(0, eUSBModeForceDevice, 0);

    //Setup the SPI interface, Normal mode, 16-bit transfer width
    SSIClockSourceSet(SSI0_BASE, SSI_CLOCK_PIOSC);
    //We can't drive the SPI from the 50Mhz system clock (for stupid technical reasons) so drive it from the 16Mhz onboard osc
    SSIConfigSetExpClk(SSI0_BASE, 16000000, SSI_FRF_MOTO_MODE_0, SSI_MODE_MASTER, 8000000, 16);
    SSIEnable(SSI0_BASE);

    //TODO we should allow the attachment of the drive over USB before it is spun up once we have drive status information
    uint32_t zero;
    while (SSIDataGetNonBlocking(SSI0_BASE, &zero)); //The SPI FIFO can be filled with junk, so pop it all out
    while (GPIOPinRead(GPIO_PORTA_BASE, GPIO_PIN_7));  //Wait for valid data from the Drive
    while (!GPIOPinRead(GPIO_PORTF_BASE, GPIO_PIN_2));  //Wait for the command FIFO (on the drive) to empty

    //Startup the USB Device
    USBDMSCInit(0, &USB_deviceStructure);


    while (1);//We could sleep, but this will do something eventually
}

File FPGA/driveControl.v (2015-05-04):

`timescale 1ns / 1ps
//////////////////////////////////////////////////////////////////////////////////
// Company: 
// Engineer: 
// 
// Create Date:    00:13:07 03/02/2015 
// Design Name: 
// Module Name:    drivePositioner 
// Project Name: 
// Target Devices: 
// Tool versions: 
// Description: 
//
// Dependencies: 
//
// Revision: 
// Revision 0.01 - File Created
// Additional Comments: 
//
//////////////////////////////////////////////////////////////////////////////////
module driveControl(
    input clk,
    input rst,
    input [15:0] SPICommandWord,
    input SPIFIFOEmpty,
    input sector_pulse,
	 input [5:0] sectorNumIn,
    input [8:0] cylNumIn,
    input sectorNumInReady,
	 input cylNumInReady,
    input headNumIn,
	 input headNumInReady,
	 input drive_ready,
	 input beginWriteNow,
	 input SPIProgFull,
	 output reg FIFOReadEnable,
    output reg inhibit_read,
    output reg writeData,
    output reg writeGate,
    output reg drive_command,
	 output drive_clock
    );
	
	reg [3:0] cnc_state;
	reg [15:0] SPICommandWordLocal;
	reg [3:0] curSPIBit;
	
	reg [15:0] driveCommandWord;
	reg [4:0] driveCommandWordCount;
	reg driveCommandInProgress;
	reg [3:0] clockDivider;
	reg drive_clock_FallingEdgeJustHappened;
	reg [3:0] writeDataPipeline;
	reg [8:0] SPIWriteWordCounter;
	
	reg [5:0] desiredSector;

	reg [15:0] compensatedWriteDataToDrive;
	reg [3:0] compensatedWriteDataToDriveCount;
	
	reg [3:0] return_state;
	
	parameter [3:0]
		CNC_INIT               	= 4'b0000, //Initialize the drive
		CNC_IDLE                = 4'b0001, //Wait here until we recieve an instruction
		CNC_DECODE              = 4'b0010, //Instruction Decode
		CNC_SEEK_CMD_SETUP      = 4'b0011, //Prepare the command to move the drive
		CNC_CMD_SECTORWAIT      = 4'b0100, //Wait for the sector pulse
		CNC_CMD_EXECUTE    	   = 4'b0101, //Issue the command to seek
		CNC_SEEK_WAIT           = 4'b0110, //Wait for drive ready
		CNC_WRITE_SETUP         = 4'b0111, //Gather the sector requested from the drive and prep the write queue
		CNC_WRITE_SYNC          = 4'b1000, //Wait for the FIFO to fill enough, then wait for our sector number to come up
		CNC_WRITE_EXECUTE       = 4'b1001; //Execute the write bits

	assign drive_clock = clockDivider[3];
	
	always @(posedge clk) begin
		if(rst) begin
			clockDivider <= 0;
			drive_clock_FallingEdgeJustHappened <= 0;
		end else begin
			clockDivider <= clockDivider + 1;
			if(clockDivider == 0) begin
				drive_clock_FallingEdgeJustHappened <= 1;
			end else begin
				drive_clock_FallingEdgeJustHappened <= 0;
			end
		end
	end
	
	always @(posedge clk) begin
		if(rst) begin
			cnc_state <= CNC_INIT;
			return_state <= CNC_IDLE;
			FIFOReadEnable <= 0;
			SPICommandWordLocal <= 16'b0;
			driveCommandWord <= 16'b0;
			driveCommandWordCount <= 5'b0;
			driveCommandInProgress <= 0;
			writeData <= 0;
			compensatedWriteDataToDriveCount <= 4'b0;
			compensatedWriteDataToDrive <= 16'b1111111111111111;
			writeDataPipeline <= 4'b0;
			desiredSector <= 6'b0;
			SPIWriteWordCounter <= 8'b0;
			curSPIBit <= 4'b0;
			writeGate <= 0;
			drive_command <= 0;
			inhibit_read <= 0;
		end else begin
			FIFOReadEnable <= 0;
			case (cnc_state)
				CNC_INIT:
				begin
					if(drive_ready) begin
						driveCommandWord[3] <= 1; //Drive Reset
						driveCommandWord[1] <= 0; //Get Status
						driveCommandWord[0] <= 1; //Sync Bit
						return_state <= CNC_IDLE;
						cnc_state <= CNC_CMD_SECTORWAIT;
					end
				end
				
				CNC_IDLE:
				begin					
					if(~SPIFIFOEmpty) begin
						SPICommandWordLocal <= SPICommandWord;
						cnc_state <= CNC_DECODE;
						FIFOReadEnable <= 1;
					end
				end
				
				CNC_DECODE:
				begin
				//NOTE Pipeline this if necessary
					cnc_state <= CNC_IDLE;
										
					case (SPICommandWordLocal[15:13]) 
					 
						3'b001: 
						begin
							cnc_state <= CNC_SEEK_CMD_SETUP;
						end
						
						3'b010:
						begin
							cnc_state <= CNC_WRITE_SETUP;
						end
					
					endcase
				end
				
				CNC_SEEK_CMD_SETUP:
				begin
					inhibit_read <= 1;
					return_state <= CNC_SEEK_WAIT;
					cnc_state <= CNC_CMD_SECTORWAIT;//Let's assume we will need to seek
					driveCommandWord[4] <= SPICommandWordLocal[10];//Pack the head number
					driveCommandWord[3] <= 0; //Drive Reset
					driveCommandWord[1] <= 0; //Get Status
					driveCommandWord[0] <= 1; //Sync Bit
					
					driveCommandWord[2] <= SPICommandWordLocal[9]; //travel direction
					driveCommandWord[15:7] <= SPICommandWordLocal[8:0];//Track delta
				end
				
				CNC_CMD_SECTORWAIT:
				begin
					if(sector_pulse) begin
						cnc_state <= CNC_CMD_EXECUTE;
					end
				end
				
				CNC_CMD_EXECUTE:
				begin
					if(~sector_pulse | driveCommandInProgress) begin
						driveCommandInProgress <= 1;
						if(drive_clock_FallingEdgeJustHappened) begin
							if(driveCommandWordCount < 16) begin //Setup the command word so the drive sees it on the next rising edge of the drive clock
								driveCommandWordCount <= driveCommandWordCount + 1;
								drive_command <= driveCommandWord[0];
								driveCommandWord <= {1'b0, driveCommandWord[15:1]};
							end else begin
								drive_command <= 0;
								driveCommandWordCount <= 5'b0;
								driveCommandWord <= 16'b0;
								driveCommandInProgress <= 0;
								cnc_state <= return_state; //We've shifted out the word, wait for the drive
							end
						end
					end
				end
				
				CNC_SEEK_WAIT:
				begin
					if(drive_ready & sector_pulse) begin
							cnc_state <= CNC_IDLE;
							inhibit_read <= 0;
					end
				end
				
				CNC_WRITE_SETUP: //Gather the sector requested from the drive and prep the write queue
				begin					
					if(~SPIFIFOEmpty) begin
						desiredSector <= SPICommandWord[5:0];
						FIFOReadEnable <= 1;
						cnc_state <= CNC_WRITE_SYNC;
					end
				end
				
				CNC_WRITE_SYNC: //Wait for the FIFO to fill enough, then wait for our sector number to come up
				begin //What an ugly combinatorial path... Some of this can be pipelined if it's necessary
					if(SPIProgFull) begin //Fist off, make sure we have a full set of data to write
						if(sectorNumInReady) begin //If the sector number from the header decoder is valid now
							if(desiredSector == sectorNumIn) begin //If we've found the winning number
								if(beginWriteNow) begin //Showtime!
									inhibit_read <= 1;
									cnc_state <= CNC_WRITE_EXECUTE;
								end
							end
						end
					end
				end
				
				//TODO This needs to be simulated
				//TODO Also, CRC is probably failing at some point
				CNC_WRITE_EXECUTE: //Execute the write bits
				begin
				
					//What should this module do?
					//133 times, read in word from FIFO
						//16 times inside that, process each bit in the word
							//16 times inside that, shift out the current bit with whatever compensation it requires
				
					//writeGate <= 1; //TODO Testing to ensure no writes occure
					if(curSPIBit == 15) begin
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

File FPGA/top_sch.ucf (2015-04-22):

//SPI Boot mode pins
CONFIG PROHIBIT = P23;
CONFIG PROHIBIT = P24;
CONFIG PROHIBIT = P25;

//SPI Variant Select Pins
CONFIG PROHIBIT = P29;
CONFIG PROHIBIT = P30;
CONFIG PROHIBIT = P31;

//PUDC_B Pull up config
CONFIG PROHIBIT = P99;

//MISO/DIN -> Q
CONFIG PROHIBIT = P51;
//CSO_B -> S_n
CONFIG PROHIBIT = P27;
//CCLK -> C
CONFIG PROHIBIT = P53;
//MOSI -> D
CONFIG PROHIBIT = P46;

//INIT_B Init done
CONFIG PROHIBIT = P48;


# Specifies the minimum (worst-case) Vccint voltage for improved timing analysis
VOLTAGE  = 1.18;

# Specifies the Vccaux voltage (Spartan-3A/6)
CONFIG VCCAUX  = 3.3;
			
NET "clk_in" TNM_NET = "clk_in";
TIMESPEC TS_clk_in = PERIOD "clk_in" 65.536 MHz HIGH 50 % INPUT_JITTER 3 ps;


NET "SPI_CommandAndWriteEmpty" LOC = P90;
NET "SPI_DataWAIT" LOC = P89;
NET "SPI_MOSI" LOC = P84;
NET "SPI_CurWordIsHeader" LOC = P88;
NET "SPI_MISO" LOC = P85;
NET "SPI_CS" LOC = P86;
NET "SPI_clk" LOC = P83;

#pin2ucf - Sun Mar 08 22:31:16 2015
#The following constraints were newly added
NET "writeData_n" LOC = P78;
NET "writeData_p" LOC = P77;
NET "drive_command_n" LOC = P44;
NET "writeGate_n" LOC = P94;
NET "writeGate_p" LOC = P93;
NET "drive_command_p" LOC = P43;
NET "drive_clock_n" LOC = P37;
NET "drive_clock_p" LOC = P36;
NET "Drive_sector_in" LOC = P82;
NET "clk_in" LOC = P41;
NET "crcInvalid" LOC = P20;
NET "drive_ready" LOC = P61;
NET "drive_sel0_n" LOC = P34;
NET "drive_sel0_p" LOC = P32;
NET "commandAndWriteFIFO_prog_full" LOC = P70;
NET "drive_sel1_n" LOC = P35;
NET "drive_sel1_p" LOC = P33;
NET "Drive_mfm_in" LOC = P98;
NET "rst_in" LOC = P21;


# PlanAhead Generated IO constraints 

NET "clk_in" IOSTANDARD = LVCMOS33;
NET "commandAndWriteFIFO_prog_full" IOSTANDARD = LVCMOS33;
NET "crcInvalid" IOSTANDARD = LVCMOS33;
NET "Drive_mfm_in" IOSTANDARD = LVCMOS33;
NET "drive_ready" IOSTANDARD = LVCMOS33;
NET "Drive_sector_in" IOSTANDARD = LVCMOS33;
NET "rst_in" IOSTANDARD = LVCMOS33;
NET "SPI_clk" IOSTANDARD = LVCMOS33;
NET "SPI_CommandAndWriteEmpty" IOSTANDARD = LVCMOS33;
NET "SPI_CS" IOSTANDARD = LVCMOS33;
NET "SPI_DataWAIT" IOSTANDARD = LVCMOS33;
NET "SPI_MISO" IOSTANDARD = LVCMOS33 | SLEW=FAST;
NET "SPI_MOSI" IOSTANDARD = LVCMOS33;
NET "SPI_CurWordIsHeader" IOSTANDARD = LVCMOS33;

NET "drive_clock_p" IOSTANDARD = LVCMOS33 | SLEW=FAST | DRIVE=16;

NET "drive_command_p" IOSTANDARD = LVCMOS33 | SLEW=FAST | DRIVE=16;
NET "drive_command_n" IOSTANDARD = LVCMOS33 | SLEW=FAST | DRIVE=16;
NET "drive_sel0_p" IOSTANDARD = LVCMOS33 | DRIVE=16;
NET "drive_sel1_p" IOSTANDARD = LVCMOS33 | DRIVE=16;
NET "writeData_p" IOSTANDARD = LVCMOS33 | SLEW=FAST | DRIVE=16;
NET "drive_clock_n" IOSTANDARD = LVCMOS33 | SLEW=FAST | DRIVE=16;

NET "drive_sel0_n" IOSTANDARD = LVCMOS33 | DRIVE=16;
NET "drive_sel1_n" IOSTANDARD = LVCMOS33 | DRIVE=16;
NET "writeData_n" IOSTANDARD = LVCMOS33 | SLEW=FAST | DRIVE=16;
NET "writeGate_p" IOSTANDARD = LVCMOS33 | SLEW=FAST | DRIVE=16;
NET "writeGate_n" IOSTANDARD = LVCMOS33 | SLEW=FAST | DRIVE=16;

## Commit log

2015-04-22 Added board files and updated readme
    [RL02Interface-B_Cu.gbl, RL02Interface-B_Mask.gbs, RL02Interface-B_SilkS.gbo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]
2015-04-22 Fixed tabs and documentation reference
    [driveControl.v]
2015-04-24 looks like KiCad's PDF generation isn't so perfect. Here's a SVG of the schematics if nothing else.
2015-04-27 Added BOM
    [BOM_PROTOTYPE.csv]
2015-05-04 Fixing up write support
    [DecodeFSM.v, driveControl.v]
2015-05-07 Added synchronizer on SPI clock
